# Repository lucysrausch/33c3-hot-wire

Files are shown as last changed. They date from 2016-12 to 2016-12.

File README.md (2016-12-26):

# 33C3 Hot Wire
Code and design files for the wireless sensor designed for a 25m long "hot wire" game.
Demo Video (sorry for German): https://www.youtube.com/watch?v=ximVu1-kXSI

## Usage
The sensor is turned on by pressing the button on the back. There is a startup melody that indicates successful startup.

If you hold the butten for > 5s, the leds flash blue. If the button is released now, the sensor shuts down and enters ultra low power mode (aka shipping mode). If you keep pressing, the sensor enters a self-test mode testing all it's components. At the beginning of the self-test, it displays the battery voltage (1,1V -> 1,5V = Red -> Green).

## Hardware
The sensor uses a MSP430 cpu, a RFM12B radio module, a Microchip StepUp and a BMA280 Accelerometer. Additionaly there are some RGB led's, a Piezo buzzer and a mechanical button on the back.

Power consumption
- Deep Sleep: ~70µA (67µA for the RFM12B...)
- Active Mode: ~500µA (127µA for the BMA280, 67µA for the RFM12B)
- Max. current (leds + buzzer + radio): 300mA

The project was design using Altium Designer 16.1. Sorry if you can't open the design files, there is also a pdf export. I'll try to export the design as an eagle project, not sure if this works.

## Software
The firmware is written using the MSP430 Energia toolchain. It uses a ported arduino library for the RFM12B by Felix Rusu. It also uses the CounterLib by Adrian Studer for measuring the wire frequency. The header files for the BMA280 are written by Helge Wurst.

The MSP430G2553 used in this project has a quiet small flash & RAM.
The code uses 14.964 Bytes (91%) of the flash memory and 414 Bytes (80%) of the RAM. Probably it could be way less...

## ToDo

- ~~add START / FINAL frequency filter with melody~~
- ~~detache accelerometer interrupt _before_ going to sleep~~
- "menu" for choosing different game modes (now all are active)
- fix ACK transmission
- implemement more game modes using the accelerometer
- actually using the comparator (hehe)

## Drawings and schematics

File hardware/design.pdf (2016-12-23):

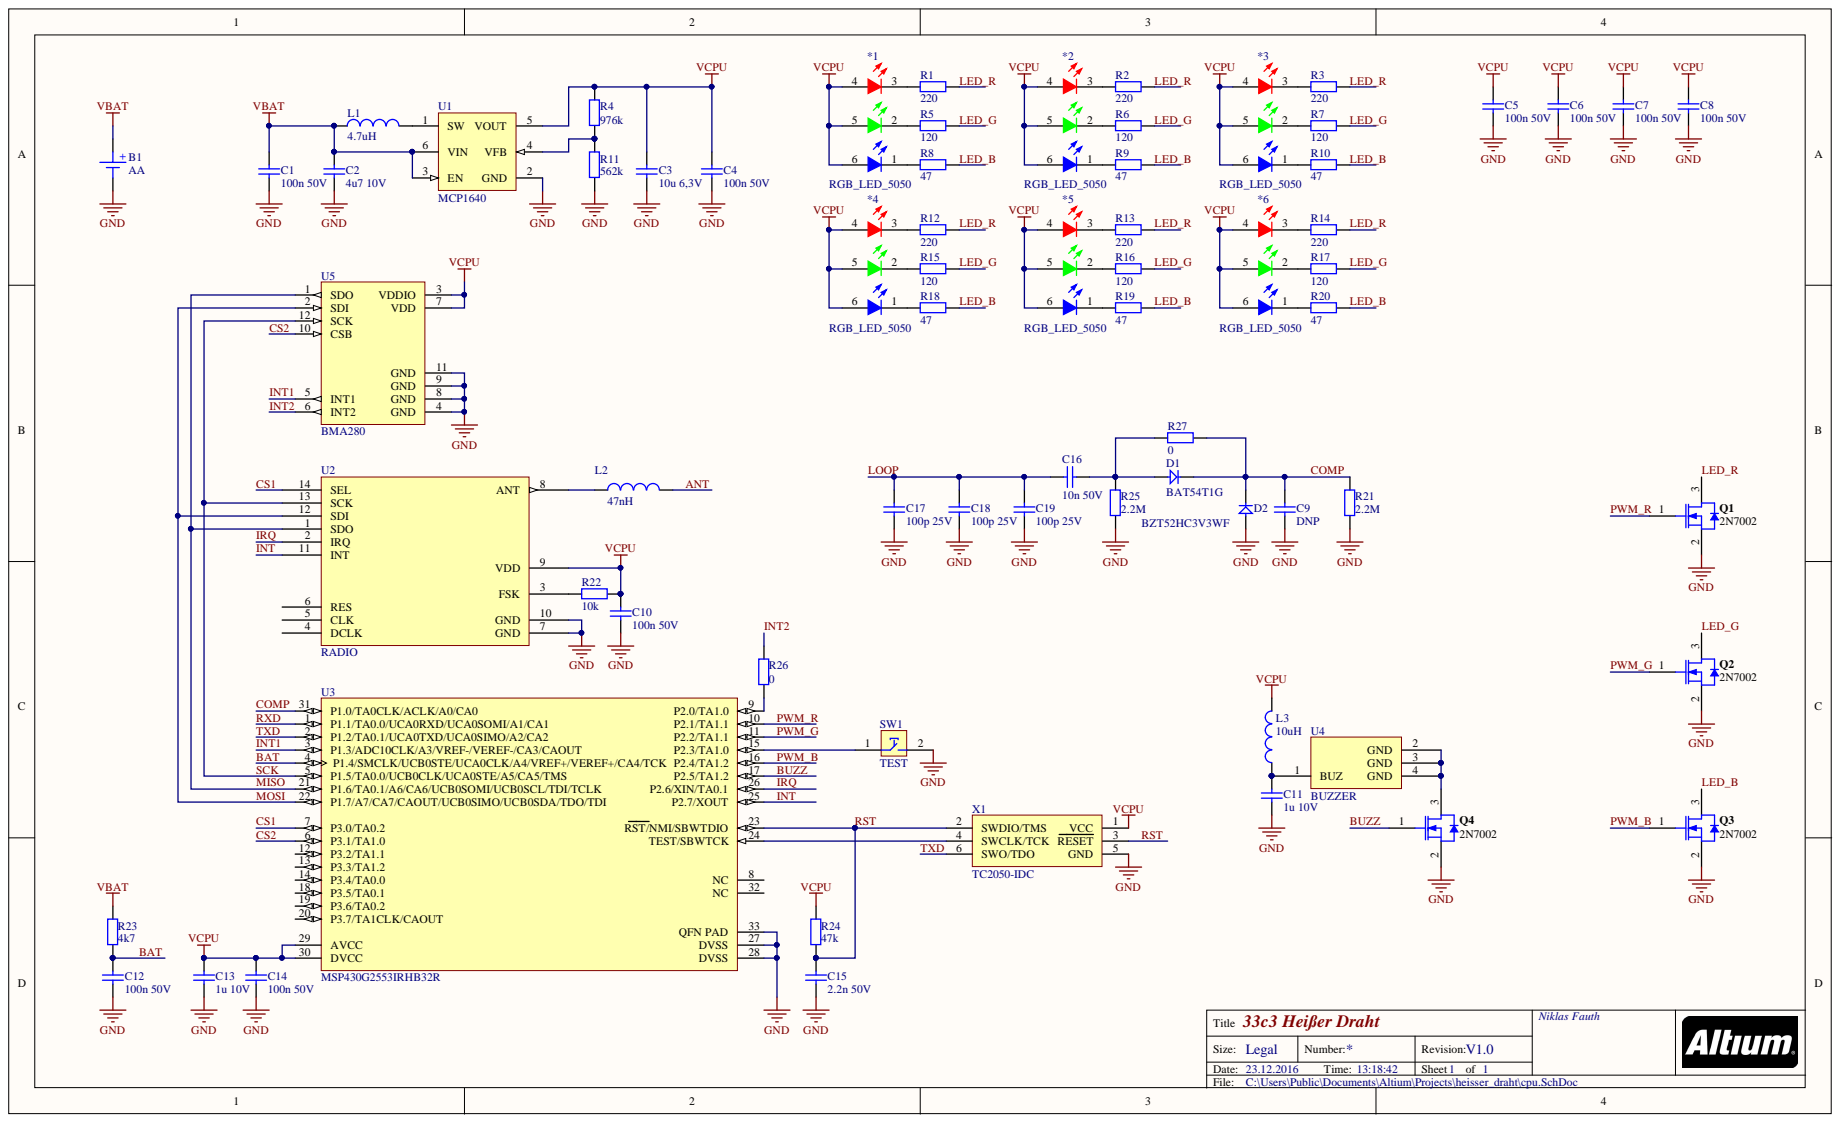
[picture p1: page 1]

SCK 12 | R27

CS2 CS1 | CSB 10

Title 33c3 Heißer Draht | Niklas Fauth

Size: Legal | Number: * | Revision: V1.0
Date: 23.12.2016 Time: 13:18:42 | | Sheet 1 of 1
File: C:\Users\Public\Documents\Altium\Projects\heisser_draht\cpu.SchDoc

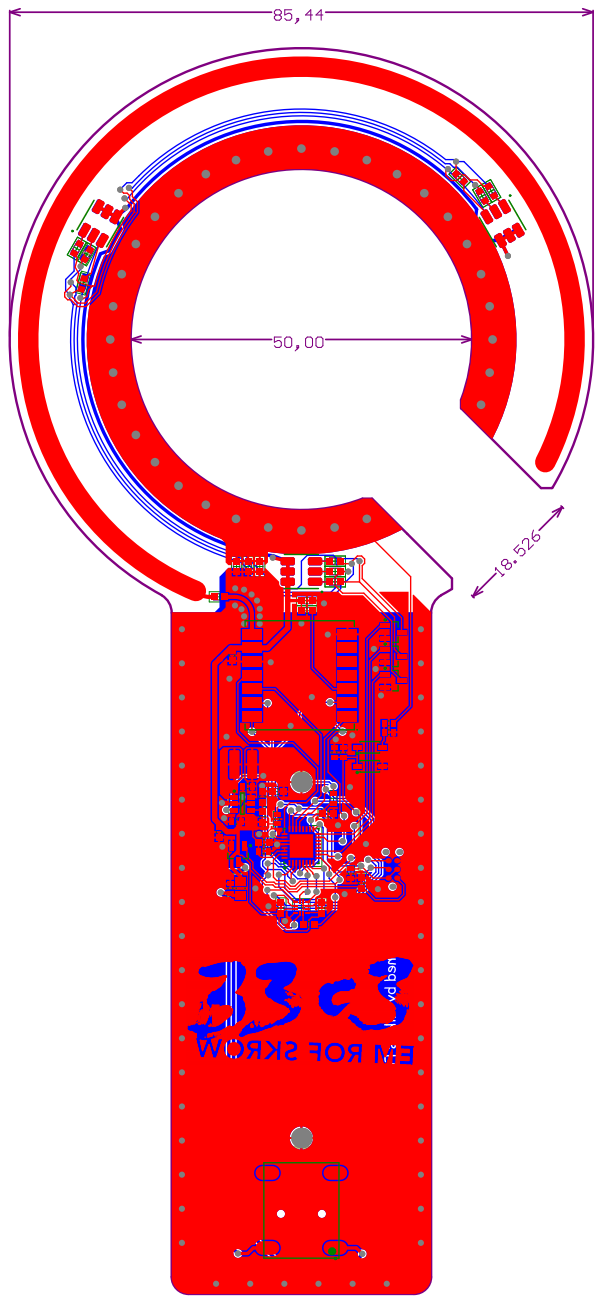
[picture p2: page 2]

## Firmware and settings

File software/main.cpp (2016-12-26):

#include <RFM12B.h>
#include <SPI.h>
#include "bma2XX_regs.h"
#include <CounterLib_t.h>

#include "Energia.h"

Counter<> freqCounter;     // create counter that counts pulses on pin P1.0

#define NODEID        42   //network ID used for this unit
#define NETWORKID     137  //the network ID we are on
#define GATEWAYID     1    //the node ID we're sending to

#define LED       //disbable modules by uncommenting
#define RADIO
#define BUZZER
#define ACC
//#define DEBUG

#define WINFREQ   500
#define STARTFREQ 100

/*
 * Gamemode 1: green. Only reacts on wire contact.
 * Gamemode 2: blue.  Triggers on wire contact, and too slow motion.
 * Gamemode 3: red.   Triggers on wire contact, too slow motion and change of oriantation.
 */
  
/* VBAT = ADC * 0,00244V
 * 614  = 1,5V
 * 574  = 1,4V
 * 533  = 1,3V
 * 492  = 1,2V
 */


#define FILTER   //prefilter for some Frequencies (100, 200, 300, 400, 500, 600kHz)

#define FREQDELAY 2   //tune this for better frequency readout
#define AQUISITION 50 //how lonh to wait for frequency measurement
#define MINFREQ 90    //lowest used frequency


#define START               digitalWrite(CS_BMA, 0)
#define STOP                digitalWrite(CS_BMA, 1)
#define READ                0x80

#define LED_G P2_4 
#define LED_R P2_2
#define LED_B P2_1

#define BUZZ P2_5

#define BUTTON P2_3

#define CS_RFM12 P3_0
#define CS_BMA   P3_1

#define ADC P1_4
#define WIRE P1_0
#define INT_BMA  P1_3


#define ACK_TIME     1500  // # of ms to wait for an ack
#define SERIAL_BAUD  9600  // serial debug baud rate
#define requestACK 0       //request ack 

#define RED 2
#define GREEN 0
#define BLUE 1

RFM12B radio;
byte sendSize = 0;
char payload[28] = ""; // max. 127 bytes
uint16_t history[3] = {0, 0, 0};


byte data[3];
boolean buttonInterrupt = false, wireInterrupt = false, accInterrupt = false;

uint16_t batVoltage = 0;
byte gameMode = 0;



  
void setup() {                
  // initialize the digital pin as an output.
  pinMode(LED_R, OUTPUT);    
  pinMode(LED_G, OUTPUT); 
  pinMode(LED_B, OUTPUT);  
  digitalWrite(LED_R, LOW);
  digitalWrite(LED_G, LOW);
  digitalWrite(LED_B, LOW);
  pinMode(BUZZ, OUTPUT);  
  digitalWrite(BUZZ, LOW);

  pinMode(ADC, INPUT); 
  analogReference(INTERNAL2V5);

  pinMode(CS_RFM12, OUTPUT);  
  digitalWrite(CS_RFM12, HIGH);

  pinMode(CS_BMA, OUTPUT);
  digitalWrite(CS_BMA, HIGH);

  #ifdef DEBUG
  Serial.begin(SERIAL_BAUD);
  Serial.print("start...");
  #endif

  SPI.begin();
  SPI.setClockDivider(2); //8MHz SPI clock

  #ifdef RADIO
  radio.Initialize(NODEID, RF12_433MHZ, NETWORKID);
  radio.Sleep(); //sleep right away to save power
  #endif

  pinMode(BUTTON, INPUT_PULLUP);
  attachInterrupt(BUTTON, buttonFunction, FALLING);  //interrupt for button

  #ifdef ACC
  bma2XXclearInterrupts(); //clear existing interrupts
  delay(100);
  bma2XXsetProfile(); //initialize Accelerometer
  //attachInterrupt(INT_BMA, accFunction, FALLING); //interrupt for BMA280
  #endif

  //pinMode(WIRE, INPUT);
  attachInterrupt(WIRE, wireFunction, CHANGE);  //interrupt for button
  

  //enableComparator();
  //_BIS_SR(LPM4_bits + GIE); //sleep, wait for interrupts
  //interrupts();
  suspend();
}

void loop() {
  if (buttonInterrupt) {
    buttonInterrupt = false;
    for (byte i = 0; i < 255; i++) { //wait ~5s
      if (digitalRead(BUTTON) != LOW) {
        delay(1000);
        if (digitalRead(BUTTON) == LOW) {
          gameMode++;
          if (gameMode > 2)
            gameMode = 0;

          if (gameMode == 0)
            detachInterrupt(INT_BMA);

          else
            attachInterrupt(INT_BMA, accFunction, FALLING);
            //noInterrupts();*/
          fail(gameMode);
        }
        return;
      }
      delay(20);
    }

    for (byte i = 0; i < 2; i++) { //indicator flashing
      digitalWrite(LED_B, HIGH);
      delay(100);
      digitalWrite(LED_B, LOW);
      delay(100);
    }
    
    delay(1000);
    
    if (digitalRead(BUTTON) != LOW) { //button still pressed?
      deepSleep(); //...then go to deep sleep
      
      #ifdef ACC   //This is the point we wake up again later
      bma2XXclearInterrupts(); 
      delay(100);
      bma2XXsetProfile();
      attachInterrupt(INT_BMA, accFunction, FALLING);
      #endif
      digitalWrite(LED_G, HIGH);
      delay(200);
      digitalWrite(LED_G, LOW);
      #ifdef BUZZER
      bootMelody(); //Windows XP boot melody ;)
      #endif
      attachInterrupt(WIRE, wireFunction, FALLING);
      return;
    }

    delay(1000); //not pressed?
    selfTest();  //then do a self test
  }

  if (wireInterrupt) {
    wireInterrupt = false;
    //CACTL1 = 0; //disable comparator
    //CACTL2 = 0;
    //reuse interrupt Pin from frequency measurement
    long currentTime = millis();
    boolean freqValid = false, freqStart = false, freqWin = false;;
    freqCounter.start(CL_Div8); //start Timer  with 8x divider
    while (millis() - currentTime < AQUISITION) {
      freqCounter.reset();
      delay(FREQDELAY);  
      history[0] = ((freqCounter.read()) / FREQDELAY * 8) / 1.28;
      if ((history[1] < history[2] + 1 || history[1] > history[2] - 1) && (history[0] < history[1] + 1 || history[0] > history[1] - 1) && history[0] > 90) { //compare three measurements
        #ifdef FILTER
        if (history[0] < 110 && history[0] > 90) {
          freqValid = true;
          #if STARTFREQ == 100
          freqStart = true;
          #endif
          #if WINFREQ == 100
          freqWin = true;
          #endif
          break;
        }

        if (history[0] < 210 && history[0] > 190) {
          freqValid = true;
          #if STARTFREQ == 200
          freqStart = true;
          #endif
          #if WINFREQ == 200
          freqWin = true;
          #endif
          break;
        }
        
        if (history[0] < 310 && history[0] > 290) {
          freqValid = true;
          #if STARTFREQ == 300
          freqStart = true;
          #endif
          #if WINFREQ == 300
          freqWin = true;
          #endif
          break;
        }
        
        if (history[0] < 410 && history[0] > 390) {
          freqValid = true;
          #if STARTFREQ == 400
          freqStart = true;
          #endif
          #if WINFREQ == 400
          freqWin = true;
          #endif
          break;
        }
        
        if (history[0] < 510 && history[0] > 490) {
          freqValid = true;
          #if STARTFREQ == 500
          freqStart = true;
          #endif
          #if WINFREQ == 500
          freqWin = true;
          #endif
          break;
        }
        
        if (history[0] < 610 && history[0] > 590) {
          freqValid = true;
          #if STARTFREQ == 600
          freqStart = true;
          #endif
          #if WINFREQ == 600
          freqWin = true;
          #endif
          break;
        }
        #endif
        
        #ifndef FILTER
        freqValid = true;
        break;
        #endif
      }
      history[2] = history[1];
      history[1] = history[0];
      delay(FREQDELAY);
    }
    freqCounter.stop(); //stop Timer
    if (!freqValid) {
      history[0] = 999;
    }
    sendPackage(2, history[0]);
    initTimers(); //restore system Timers
    if (freqStart) {
      startMelody();
    }
    else if (freqWin) {
      for (byte i = 0; i < 2; i++) { //indicator flashing
      digitalWrite(LED_B, HIGH);
      digitalWrite(LED_R, HIGH);
      delay(100);
      digitalWrite(LED_B, LOW);
      digitalWrite(LED_R, LOW);
      delay(100);
    }
      winMelody();
    }
    else {
      fail(gameMode);
    }
    pinMode(WIRE, INPUT);
    attachInterrupt(WIRE, wireFunction, CHANGE);
  }

  if (accInterrupt) {
    accInterrupt = false;
    char intType = readBMA2XX(BMAREG_INTSTAT0); //Read the Interrupt Reason
    if (bitRead(intType, INTSTAT0_FLATINT) && gameMode == 2) {   //Oriantation changed
      sendPackage(11, 0);
      fail(gameMode);
    }
    else if (bitRead(intType, INTSTAT0_SLOPEINT)) { //Fast motion Interrupt
      sendPackage(12, 0);
      //fail();
    }
    else if (bitRead(intType, INTSTAT0_SLO_NO_MOT_INT) && gameMode > 0) { //Slow Motion interrupt
      sendPackage(13, 0);
      fail(gameMode);
    }
  }

  //enableComparator();
  interrupts();//reenable interrupts
  //go back to sleep
  suspend();
}

void selfTest() {
  uint16_t batVoltage = readBat();

  #ifdef LED
  analogWrite(LED_R, constrain(map(batVoltage, 490, 615, 255, 0), 0, 255)); //display the Battery voltage (1,1V - 1,5V ^= Red - Green)
  analogWrite(LED_G, constrain(map(batVoltage, 490, 615, 0, 255), 0, 255));
  delay(1000);
  digitalWrite(LED_R, LOW);
  digitalWrite(LED_G, LOW);
    
  for(int j=0; j<512; j++) { //test LED's
    if (j % 512 < 256)
      analogWrite(LED_R, j % 256);
    else
      analogWrite(LED_R, 256 - j % 256);
  delay(1);
  }
  digitalWrite(LED_R, LOW);
  for(int j=0; j<512; j++) {
    if (j % 512 < 256)
      analogWrite(LED_G, j % 256);
    else
      analogWrite(LED_G, 256 - j % 256);
  delay(1);
  digitalWrite(LED_G, LOW);
  }
  for(int j=0; j<512; j++) {
    if (j % 512 < 256)
      analogWrite(LED_B, j % 256);
    else
      analogWrite(LED_B, 256 - j % 256);
  delay(1);
  }
  digitalWrite(LED_B, LOW);
  delay(500);
  #endif

  #ifdef BUZZER //test Buzzer
  tone(BUZZ, 2200);
  delay(100);
  tone(BUZZ, 2700);
  delay(100);
  tone(BUZZ, 3200);
  delay(100);
  noTone(BUZZ);
  delay(500);
  #endif
  
  delay(500);

  sendPackage(1, 0); //test Radio 
  
  digitalWrite(LED_G, HIGH);
  delay(200);
  digitalWrite(LED_G, LOW);
}

void deepSleep() {
  detachInterrupt(WIRE);
  detachInterrupt(INT_BMA);
  #ifdef BUZZER
  shutdownMelody(); //Windows XP shutdown melody ;)
  #endif
  #ifdef RADIO
  radio.Sleep();
  #endif
  #ifdef ACC
  writeBMA2XX(BMAREG_SLEEP_DURATION, 0b10 << BMA_LOWPOWER_ENA); //go to suspend mode (~2µA)
  #endif
  interrupts(); //enable interrupts to capture button press
  //_BIS_SR(LPM4_bits + GIE);   //low power mode
  suspend();
}

/*
void Wheel(byte WheelPos, byte pdata[]) { //HSV color table thingy
  if(WheelPos < 85) {
    pdata[0] = WheelPos * 3;
    pdata[1] = 255 - WheelPos * 3;
    pdata[2] = 0;
   return;
  } else if(WheelPos < 170) {
   WheelPos -= 85;
    pdata[0] = 255 - WheelPos * 3;
    pdata[1] = 0;
    pdata[2] = WheelPos * 3;
   return;
  } else {
   WheelPos -= 170;
   pdata[0] = 0;
   pdata[1] = WheelPos * 3;
   pdata[2] = 255 - WheelPos * 3;
   return;
  }
}*/

void fail(byte color) { //fail sound...

  #ifdef ACC
  //detachInterrupt(INT_BMA);
  delay(5);
  #endif
  for (byte i = 0; i < 5; i++) {
    if (color == RED)
    digitalWrite(LED_R, HIGH);
    else if (color == GREEN)
    digitalWrite(LED_G, HIGH);
    else if (color == BLUE)
    digitalWrite(LED_B, HIGH);
    #ifdef BUZZER
    tone(BUZZ, 3200);
    #endif
    delay(100);
    if (color == RED)
    digitalWrite(LED_R, LOW);
    if (color == GREEN)
    digitalWrite(LED_G, LOW);
    if (color == BLUE)
    digitalWrite(LED_B, LOW);
    noTone(BUZZ);
    delay(100);
  } 
  #ifdef ACC
  delay(5);
  //attachInterrupt(INT_BMA, accFunction, FALLING);
  #endif
}

void wireFunction() //ISR
{
  detachInterrupt(WIRE);
  wakeup();
  noInterrupts();
  wireInterrupt = true;
}

void buttonFunction() //ISR
{
  wakeup();
  noInterrupts();
  buttonInterrupt = true;
}

void accFunction() //ISR
{
  wakeup();
  noInterrupts();
  accInterrupt = true;
}

void startMelody() {}

#define WINSLEEP 600

void winMelody() {
  tone(BUZZ, 196);
  delay(WINSLEEP/4);
  tone(BUZZ, 262);
  delay(WINSLEEP/4);
  tone(BUZZ, 330);
  delay(WINSLEEP/4);
  tone(BUZZ, 392);
  delay(WINSLEEP/4);
  tone(BUZZ, 523);
  delay(WINSLEEP/4);

  tone(BUZZ, 784);
  delay(WINSLEEP/2);
  tone(BUZZ, 659);
  delay(WINSLEEP/2);

  // put your setup code here, to run once:
  tone(BUZZ, 207);
  delay(WINSLEEP/4);
  tone(BUZZ, 261);
  delay(WINSLEEP/4);
  tone(BUZZ, 311);
  delay(WINSLEEP/4);
  tone(BUZZ, 415);
  delay(WINSLEEP/4);
  tone(BUZZ, 523);
  delay(WINSLEEP/4);
  tone(BUZZ, 622);
  delay(WINSLEEP/4);

  tone(BUZZ, 830);
  delay(WINSLEEP/2);
  tone(BUZZ, 659);
  delay(WINSLEEP/2);

  // put your setup code here, to run once:
  tone(BUZZ, 233);
  delay(WINSLEEP/4);
  tone(BUZZ, 293);
  delay(WINSLEEP/4);
  tone(BUZZ, 349);
  delay(WINSLEEP/4);
  tone(BUZZ, 466);
  delay(WINSLEEP/4);
  tone(BUZZ, 587);
  delay(WINSLEEP/4);
  tone(BUZZ, 698);
  delay(WINSLEEP/4);

  tone(BUZZ, 932);
  delay(WINSLEEP/2);
  noTone(BUZZ);
  delay(WINSLEEP/32);
  tone(BUZZ, 988);
  delay(WINSLEEP/4);
  noTone(BUZZ);
  delay(WINSLEEP/32);
  tone(BUZZ, 988);
  delay(WINSLEEP/4);
  noTone(BUZZ);
  delay(WINSLEEP/32);
  tone(BUZZ, 988);
  delay(WINSLEEP/4);
  noTone(BUZZ);
  delay(WINSLEEP/32);

  tone(BUZZ, 1046);
  delay(WINSLEEP);
  noTone(BUZZ);
}
/*
__attribute__((interrupt(COMPARATORA_VECTOR))) //ISR
void ComparatorISR(void)
{ 
  wakeup();
  noInterrupts();
  wireInterrupt = true;
}

void enableComparator() { //TODO
  //WDTCTL = WDTPW + WDTHOLD; 
  CACTL2 = CAF + P2CA0; //no short, CA0 on -, digital Filter

  CACTL1 = CAON + CAREF_3 + CAIE + CAIES; //comparator enabled, internal diode reference, comparator interrupt enabled, rising edge interrupt
}
*/
uint16_t readBat() {
  for (byte i = 0; i < 3; i++) { //read multiple times for better Accuracy, espacially after deep sleep
    batVoltage = analogRead(ADC);
    delay(5);
  }  

  if (batVoltage < 490) {
    errorBlink(4);
    deepSleep();
  }
  return batVoltage;
}

void sendPackage(byte reason, uint16_t freq) { //package handler
  uint8_t bat = constrain(map(readBat(), 490, 615, 0, 99), 0, 99);
  #ifdef RADIO
  snprintf(payload, 28, "ID:%02d;INT:%02d;BAT:%02d;F:%03d;", NODEID, reason, bat, freq);
  radio.Wakeup();
  radio.Send(GATEWAYID, payload, strlen(payload) + 1, requestACK);
  memset(payload, 0, sizeof(payload));
  #if requestACK
  if (waitForAck()) Serial.print("ok!");
  else {
    errorBlink(3);
  }
  #endif
  #endif
}

void errorBlink(byte code) { //error blink sequence
  for (byte i = 0; i < code; i++) {
    digitalWrite(LED_R, HIGH);
    #ifdef BUZZER
    tone(BUZZ, 3200);
    #endif
    delay(100);
    digitalWrite(LED_R, LOW);
    noTone(BUZZ);
    delay(100);
  }
}

void shutdownMelody() { 
  tone(BUZZ, 1661);
  delay(300);
  tone(BUZZ, 1244);
  delay(300);
  tone(BUZZ, 830);
  delay(300);
  tone(BUZZ, 932);
  delay(300);
  noTone(BUZZ);
}

void bootMelody() {
  tone(BUZZ, 1661);
  delay(225);
  tone(BUZZ, 622);
  delay(150);
  tone(BUZZ, 932);
  delay(300);
  tone(BUZZ, 830);
  delay(450);
  tone(BUZZ, 1661);
  delay(300);
  tone(BUZZ, 932);
  delay(600);
  noTone(BUZZ);  
}

#if requestACK
// wait a few milliseconds for proper ACK, return true if received
static bool waitForAck() {
  long now = millis();
  while (millis() - now <= ACK_TIME)
    if (radio.ACKReceived(GATEWAYID))
      return true;
  return false;
}
#endif

void bma2XXclearInterrupts()
{
  // clear interrupt enable flags
  writeBMA2XX(BMAREG_DETECT_OPTS1, 0x00);
  writeBMA2XX(BMAREG_DETECT_OPTS2, 0x00);
  // clear mapping
  writeBMA2XX(BMAREG_INT_MAP1, 0x00);
  writeBMA2XX(BMAREG_INT_MAP2, 0x00);
  writeBMA2XX(BMAREG_INT_MAP3, 0x00);
  // set pins tri-state 
  writeBMA2XX(BMAREG_INTPIN_OPTS, (INTPIN_ACTIVE_LO<<INTPIN_INT1_ACTLVL) | (INTPIN_OPENDRIVE<<INTPIN_INT1_DRV) | // make pins active low and open-collector ~ tri-state
                     (INTPIN_ACTIVE_LO<<INTPIN_INT2_ACTLVL) | (INTPIN_OPENDRIVE<<INTPIN_INT2_DRV) ); 
                   
  writeBMA2XX(BMAREG_INT_CTRL_LATCH, 1 << BMA_RESET_INT); // setting this clears any latched interrupts  
}

void bma2XXsetProfile()
{

  writeBMA2XX(BMAREG_SLEEP_DURATION, 0x00);// deactivate sleep mode
  delayMicroseconds(500); //SUSPEND/LPM1: a > 450us delay is required between writeBMA2XX transactions
  bma2XXclearInterrupts();
  
  //perform a soft reset, wait >30ms
  writeBMA2XX(BMAREG_SOFTRESET, BMA_SOFTRESET_MAGICNUMBER);
  delay(50); //wait for soft reset to complete
  
  writeBMA2XX(BMAREG_BANDWIDTH, BW_500Hz);     //500 Hz BW, 1000 samples per second
  writeBMA2XX(BMAREG_ACC_RANGE, ACC_2g);
  
  writeBMA2XX(BMAREG_INT_CTRL_LATCH, 0b1011); //set interrupt resetting behavior: temporary 1ms (active low)
  
  writeBMA2XX(BMAREG_DETECT_OPTS1, (1<<DO_FLAT_EN));//(1<<DO_SLOPE_Z_EN) | (1<<DO_SLOPE_Y_EN) | (1<<DO_SLOPE_X_EN) | (1<<DO_FLAT_EN)); //enable Slope and Flat Interrupt
  writeBMA2XX(BMAREG_SLOPE_THRESHOLD, (char)(15)); //configure slope detection: ds 4.8.5
  writeBMA2XX(BMAREG_SLOW_THRESHOLD, (char)(10)); //configure slow motion detection
  writeBMA2XX(BMAREG_SLOPE_DURATION, 0b00001011); //configure slope detection: ds 4.8.5
  
  writeBMA2XX(BMAREG_DETECT_OPTS3, (1<<DO_SLO_NO_MOT_SEL) | (1<<DO_SLO_NO_MOT_Z_EN)|(1<<DO_SLO_NO_MOT_X_EN)|(1<<DO_SLO_NO_MOT_Y_EN)); //no motion on all axis
  
  writeBMA2XX(BMAREG_INT_MAP1, 1<<MAP_INT1_FLAT | 1<<MAP_INT1_NO_MOTION | 1<<MAP_INT1_SLOPE);  // ap FLAT and No motion interrupt to INT1 pin
  writeBMA2XX(BMAREG_INTPIN_OPTS, (INTPIN_ACTIVE_LO<<INTPIN_INT1_ACTLVL) | (INTPIN_PUSHPULL<<INTPIN_INT1_DRV) |
                     (INTPIN_ACTIVE_LO<<INTPIN_INT2_ACTLVL) | (INTPIN_PUSHPULL<<INTPIN_INT2_DRV) ); //pins are active low and push-pull mode      

  writeBMA2XX(BMAREG_SLEEP_DURATION, 1 << BMA_LOWPOWER_ENA); //go to low power Mode
}

char readBMA2XX(uint8_t address)
{
  //returns the contents of any 1 byte register from any address
  char buf;

  START;
  SPI.transfer(address|READ);
  buf = SPI.transfer(0xFF);
  STOP;
  return buf;
}



void writeBMA2XX(uint8_t address, char data)
{
  //write any data byte to any single address
  START;
  SPI.transfer(address);
  SPI.transfer(data);
  STOP;

  delayMicroseconds(2);
}

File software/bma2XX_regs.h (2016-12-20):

#include <inttypes.h>
#include <stdbool.h>

/*
 * Register transcription by Helge Wurst
 */

#ifndef _BMA2XX_REGS_H_
#define _BMA2XX_REGS_H_

  #define BMAREG_FIFO_DATA_OUT 0x3F // (BMA255/280 only)
  #define BMAREG_FIFO_CONFIG   0x3E // (BMA255/280 only)
  #define BMA_FIFO_MODE_BYPASS  (0b00 << 6)// (BMA255/280 only)
  #define BMA_FIFO_MODE_FIFO    (0b01 << 6)// (BMA255/280 only)
  #define BMA_FIFO_MODE_STREAM  (0b10 << 6)// (BMA255/280 only)
  #define BMA_FIFO_DATA_SEL_XYZ (0b00 << 0)// (BMA255/280 only)
  #define BMA_FIFO_DATA_SEL_X_ONLY (0b01 << 0)// (BMA255/280 only)
  #define BMA_FIFO_DATA_SEL_Y_ONLY (0b10 << 0)// (BMA255/280 only)
  #define BMA_FIFO_DATA_SEL_Z_ONLY (0b11 << 0)// (BMA255/280 only)
  
  #define BMAREG_OFFSET_FILT_Z 0x3D // _BMA250_ only!
  #define BMAREG_GP1       0x3C //  (BMA255/280 only)
  #define BMAREG_OFFSET_FILT_Y 0x3C // _BMA250_ only!
  #define BMAREG_GP0       0x3B //  (BMA255/280 only)
  #define BMAREG_OFFSET_FILT_X 0x3B // _BMA250_ only!

  #define BMAREG_OFFSET_Z 0x3A
  #define BMAREG_OFFSET_Y 0x39
  #define BMAREG_OFFSET_X 0x38
  
  #define BMAREG_UNDEF1 0x37
  #define BMAREG_UNDEF2 0x36
  
  #define BMAREG_INTERFACE_CFG 0x34
  #define IFCON_I2C_WDT_EN  2
  #define IFCON_I2C_WDT_SEL 1
  #define IFCON_SPI_3WIRE   0

  #define BMAREG_NVM 0x33
  #define NVM_REMAIN    4 // (BMA255/280 only) bits 7:4
  #define NVM_LOAD    3
  #define NVM_READY   2
  #define NVM_PROG_TRIG 1
  #define NVM_PROG_MODE 0
  
  // BMA2XX register map, bits and values
  #define BMAREG_SELF_TEST 0x32
  #define SELF_TEST_Z 0b11
  #define SELF_TEST_Y 0b10
  #define SELF_TEST_X 0b01
  #define SELF_TEST_OFF 0b00
  #define SELF_TEST_SIGN_POSITIVE 0b000
  #define SELF_TEST_SIGN_NEGATIVE 0b100
  
  #define BMAREG_FIFO_WATERMARK 0x30 // BMA255/280 only
  #define FIFOCFG_WATERMARKLVL_TRIG 0 // bits 5:0
  #define BMAREG_FLAT1 0x2F
  #define FLAT_HOLD_TIME  4 // bits 5:4 // incomplete def
  #define FLAT_HYST   0 // bits 2:0 // incomplete def
  #define BMAREG_FLAT0 0x2E
  #define FLAT_THETA 0 // bits 5:0
  #define BMAREG_ORIENT1 0x2D
  #define ORIENT_UD_EN 6 // (BMA255/280 only)
  #define ORIENT_THETA 0 // bits 5:0
  #define BMAREG_ORIENT0 0x2C
  #define ORIENT_HYST (0b000 << 4) // incomplete def
  #define ORIENT_BLOCKING (0b00 << 2) // incomplete def
  #define ORIENT_MODE (0b00 << 0) // incomplete def
  #define BMAREG_TAP_OPT_THR 0x2B
  #define TAP_SAMPLES_16 (0b11<<6)
  #define TAP_SAMPLES_8  (0b10<<6)
  #define TAP_SAMPLES_4  (0b01<<6)
  #define TAP_SAMPLES_2  (0b00<<6)
  #define TAP_THR 0 // bits 4:0 occupy tap_threshold, see ds
  #define BMAREG_TAP_OPT_DUR 0x2A
  #define TAP_QUIET 7
  #define TAP_SHOCK 6
  // bits 3:0 occupy tap_dur, see ds
  #define BMAREG_SLO_NO_MOT 0x29 // (BMA255/280 only)
  #define BMAREG_SLOPE_THRESHOLD 0x28
  #define BMAREG_SLOW_THRESHOLD 0x29
  #define BMAREG_SLOPE_DURATION 0x27
  #define BMAREG_HIGH_THRESHOLD 0x26
  #define BMAREG_HIGH_DURATION 0x25
  #define BMAREG_MODE_HYST  0x24
  #define HM_HI1      7 // swap for options in ds on demand
  #define HM_HI0      6
  #define HM_LOW_MODE 2
  #define HM_LO1      1 // swap for options in ds on demand
  #define HM_LO0      0
  #define BMAREG_LOW_THRESHOLD 0x23
  #define BMAREG_LOW_DURATION 0x22

  #define BMAREG_INT_CTRL_LATCH    0x21 // interrupt monostable time or latching settings (bit 3:0 settings: ds table 14)
  #define BMA_RESET_INT    7 // setting this clears any latched interrupts
  // bits 3:0 : interrupt signal mode (see below)
  #define INTMODE_NONLATCHED 0b0000
  #define INTMODE_TEMP250ms  0b0001
  #define INTMODE_TEMP500ms  0b0010
  #define INTMODE_TEMP1s     0b0011
  #define INTMODE_TEMP2s     0b0100
  #define INTMODE_TEMP4s     0b0101
  #define INTMODE_TEMP8s     0b0110
  #define INTMODE_LATCHED    0b0111
  #define INTMODE_TEMP500us  0b1001
  #define INTMODE_TEMP1ms    0b1011
  #define INTMODE_TEMP12ms   0b1100 // 12.5 millisecs
  #define INTMODE_TEMP25ms   0b1101
  #define INTMODE_TEMP50ms   0b1110
  #define BMAREG_INTPIN_OPTS 0x20 // interrupt output drive modes. Use open-drive + active lo for TWI compliance
  #define INTPIN_INT2_DRV    3 // 0: open-drive, 1: push-pull
  #define INTPIN_INT2_ACTLVL 2 // set to '0' for active high mode
  #define INTPIN_INT1_DRV    1 // 0: open-drive, 1: push-pull
  #define INTPIN_INT1_ACTLVL 0 // set to '0' for active high mode
  #define INTPIN_ACTIVE_HI 0x01
  #define INTPIN_ACTIVE_LO 0x00
  #define INTPIN_PUSHPULL  0x00
  #define INTPIN_OPENDRIVE 0x01
  #define BMAREG_INT_MAP3 0x1B
  #define MAP_INT2_FLAT       7
  #define MAP_INT2_ORIENT     6
  #define MAP_INT2_SINGLE_TAP 5
  #define MAP_INT2_DOUBLE_TAP 4
  #define MAP_INT2_SLOPE      2
  #define MAP_INT2_HI         1
  #define MAP_INT2_LO         0
  #define BMAREG_INT_MAP2 0x1A
  #define MAP_INT2_DATA 7
  #define MAP_INT1_DATA 0
  #define BMAREG_INT_MAP1 0x19
  #define MAP_INT1_FLAT       7
  #define MAP_INT1_ORIENT     6
  #define MAP_INT1_SINGLE_TAP 5
  #define MAP_INT1_DOUBLE_TAP 4
  #define MAP_INT1_NO_MOTION 3
  #define MAP_INT1_SLOPE      2
  #define MAP_INT1_HI         1
  #define MAP_INT1_LO         0
  #define BMAREG_DETECT_OPTS3 0x18  // (BMA255/280 only)
  #define DO_SLO_NO_MOT_SEL 3 // (BMA255/280 only)
  #define DO_SLO_NO_MOT_Z_EN  2 // (BMA255/280 only)
  #define DO_SLO_NO_MOT_Y_EN  1 // (BMA255/280 only)
  #define DO_SLO_NO_MOT_X_EN  0 // (BMA255/280 only)
  
  #define BMAREG_DETECT_OPTS2 0x17
  #define DO_FIFO_WM_EN 6   // (BMA255/280 only)
  #define DO_FIFO_FULL_EN 5 // (BMA255/280 only)
  #define DO_NEW_DATA_EN 4
  #define DO_LOW_EN      3
  #define DO_HIGH_Z_EN   2
  #define DO_HIGH_Y_EN   1
  #define DO_HIGH_X_EN   0
  #define BMAREG_DETECT_OPTS1 0x16
  #define DO_FLAT_EN       7
  #define DO_ORIENT_EN     6
  #define DO_SINGLE_TAP_EN 5 // only one tap mode is allowed at a time
  #define DO_DOUBLE_TAP_EN 4
  #define DO_SLOPE_Z_EN    2 // motion detection can be enabled for each axis individually
  #define DO_SLOPE_Y_EN    1
  #define DO_SLOPE_X_EN  0
  // - 0x15 reserved -
  #define BMAREG_SOFTRESET 0x14
  #define BMA_SOFTRESET_MAGICNUMBER 0xB6 // writing this number to 0x14 triggers a soft reset (30-40ms wait time?)
  
  #define BMAREG_DATA_ACQUISITION 0x13
  #define DISABLE_LOW_PASS_FILTERING 7 // data_high_bandwidth option for unfiltered AD values to output the unfiltered datastream (default: filtering enabled (0))
  #define DISABLE_SHADOWING 6 // with shadowing enabled, >8bit data is double buffered to get consisting low/high byte values.
  
  #define BMAREG_LOWPOWER 0x12      // (BMA255/280 only)
  #define LPWR_LOWPOWER_MODE    6 // (BMA255/280 only), set to 1 for BMA250 legacy mode (default is 0 :( )
  #define LPWR_LOWPOWER_MODE1   0b0 // (0 << LPWR_LOWPOWER_MODE) // (BMA255/280 only)
  #define LPWR_LOWPOWER_MODE2   0b1 // (1 << LPWR_LOWPOWER_MODE) // (BMA255/280 only)
  #define LPWR_SLEEPTIMER_MODE   5  // (BMA255/280 only), set to 0 for BMA250 legacy mode (default is 0 :( )
  #define LPWR_SLEEPMODE_EVENT_DRIVEN 0b0 // (BMA255/280 only)
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

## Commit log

2016-12-21 ADD: Frequency measurent of the wire signal for sensor localisation
2016-12-23 UPD: design files, added BMA280
    [hot_wire.PrjPcb, main.SchDoc, main.sch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]
2016-12-26 ADD: Mario level complete melody for end of wire
2016-12-26 UPD: actual test & corrections, espacially Interrupt handling
    [main.cpp]
